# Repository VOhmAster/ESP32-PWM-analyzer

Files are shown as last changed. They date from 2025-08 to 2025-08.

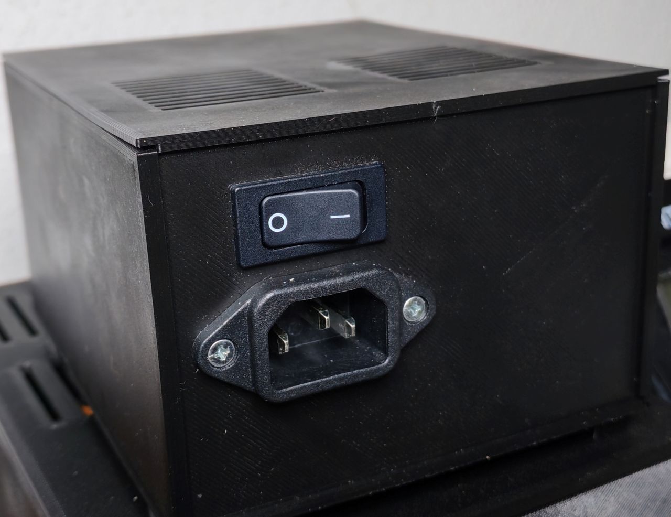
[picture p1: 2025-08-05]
Images/IMG_5.jpg

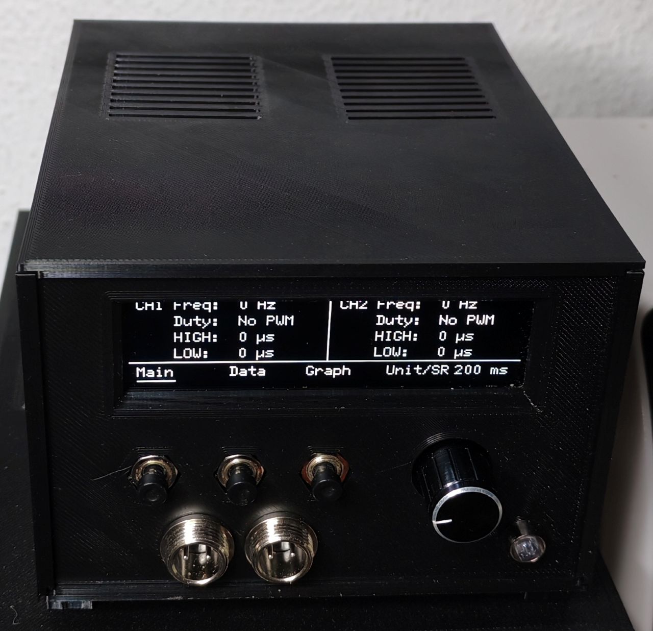
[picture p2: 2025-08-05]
Images/IMG_1.jpg

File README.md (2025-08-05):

# PWM Signal Analyzer

## Description
This project demonstrates a method of analyzing PWM signals with a focus on graphical, real-time visualization of the waveform. The main goal is to educate users on PWM analysis and provide a visual representation of signals as they change in real-time.

## **Features**
- **Real-time graphical display** of PWM waveforms
- **Adjustable frequency zoom levels** for different ranges (300 Hz – 2 MHz)
- **Simple user interface** with interactive menu options
- **Supports multiple PWM channels** (CH1, CH2)
- **Visual glitch detection** in the signals
- **Freeze mode** to stop updates for stable readings

### **Displayed Measurements**
- **Main Menu**
  - Frequency
  - Duty Cycle
  - High Time
  - Low Time
- **Data Menu**
  - Pulse Width
  - Period *(auto-switches between µs / ms based on value)*
  - Rise-to-Rise Interval
  - Glitch Count

## Additional Feature
The onboard RGB LED acts as a status indicator, adapting its color and behavior (pulsing or blinking) according to the current channel activity, frequency ranges, and duty cycle states.

## Hardware  
This project is built on an **ESP32-S3** and uses the following components:  
- **Two PWM signal inputs** (with optional RC delay network and 10k pull-down to GND).  
- **SSD1322 OLED display** (SPI interface).  
- **Rotary encoder** to adjust the update interval.  
- **Button interface** for menu navigation (3 dedicated buttons).  
- **RGB LED** as a status indicator (color and blink patterns show channel activity and duty states).  
- **220V → 5V (≥700 mA) power supply** power supply module.  
- **STDN-3A24-ADJ step-down module** for voltage regulation.  

### Pin Configuration
| Name | Pin | Description |
|---|-----|---|
| `PWM1_PIN` | 45  | Channel 1 PWM input |
| `PWM2_PIN` | 46  | Channel 2 PWM input |
| `ENC_A` | 17  | Rotary encoder pin A |
| `ENC_B` | 18  | Rotary encoder pin B |
| `ENC_SW` | 9 | Rotary encoder switch |
| `RED_PIN` | 37  | Red LED for status |
| `GREEN_PIN` | 36  | Green LED for status |
| `BLUE_PIN` | 38  | Blue LED for status |
| `SPI_MOSI_PIN` | 11  | OLED MOSI |
| `SPI_SCK_PIN` | 12  | OLED SCK |
| `SPI_CS_PIN` | 10  | OLED CS |
| `SPI_RES_PIN` | 13  | OLED Reset |
| `SPI_DC_PIN` | 14  | OLED DC |
| `BTN_MENU1` | 20  | Main menu |
| `BTN_MENU2` | 21  | Detailed data |
| `BTN_MENU3` | 47  | Graphical view |

### Important Notes
- A 10kΩ pull-down resistor is placed on the PWM input pins to improve signal stability and ensure reliable readings during startup.

## Installation
1. Clone the repository to your local machine:
    ```bash
    git clone https://github.com/VOhmAster/ESP32-PWM-analyzer.git
    ```
2. Open the project in Arduino IDE.
3. Upload the code to your ESP32 device.
4. Connect the PWM signal sources to the appropriate pins.

## Usage
- **Encoder Rotation**: Adjust the update interval between 50ms and 2000ms or toggle Freeze mode.
- **Encoder Button**: Change the display unit (Hz → kHz → MHz → Hz).
- **Display Navigation**: Use the dedicated buttons to switch between:
- **Main Display**: Displays real-time PWM signal data.
- **Detailed Data**: Shows more in-depth measurements such as high and low times.
- **Graph View**: Displays the waveform graph of the signals.
    
## Expansion
This project can be expanded by adding more hardware, allowing for higher-frequency PWM analysis and additional features like:
- Signal filtering and smoothing.
- Support for higher frequency ranges beyond the default setup.

## Files Included
- `PWM_analyzer.ino`: Main Arduino code.
- `Schematics/`: EasyEDA design files.
- `3D_Models/`: STL files for 3D printing the enclosure.

## Demo

**Load Response:**  
Load response

**Boot Sequence:**  
Boot

**OTA Firmware Update:**  
OTA

## License
This project is licensed under the MIT License - see the [LICENSE](LICENSE) file for details.

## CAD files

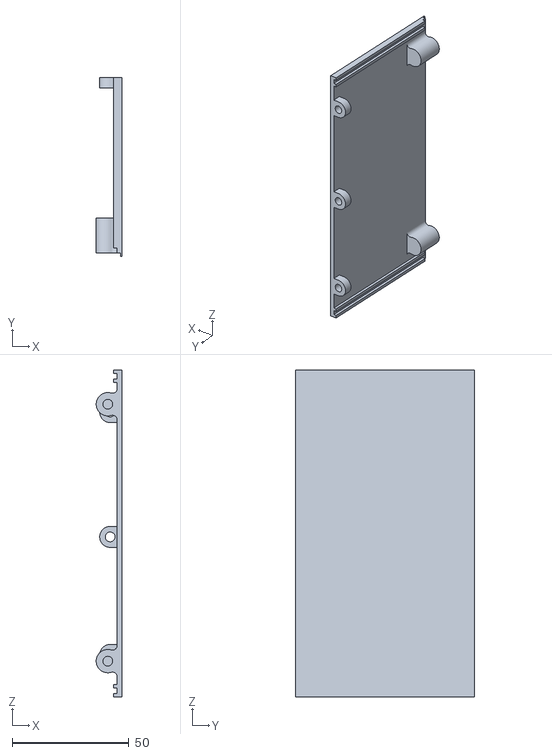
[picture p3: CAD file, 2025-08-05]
3D-models/Right_panel.stl
11.0 x 76.5 x 140.0

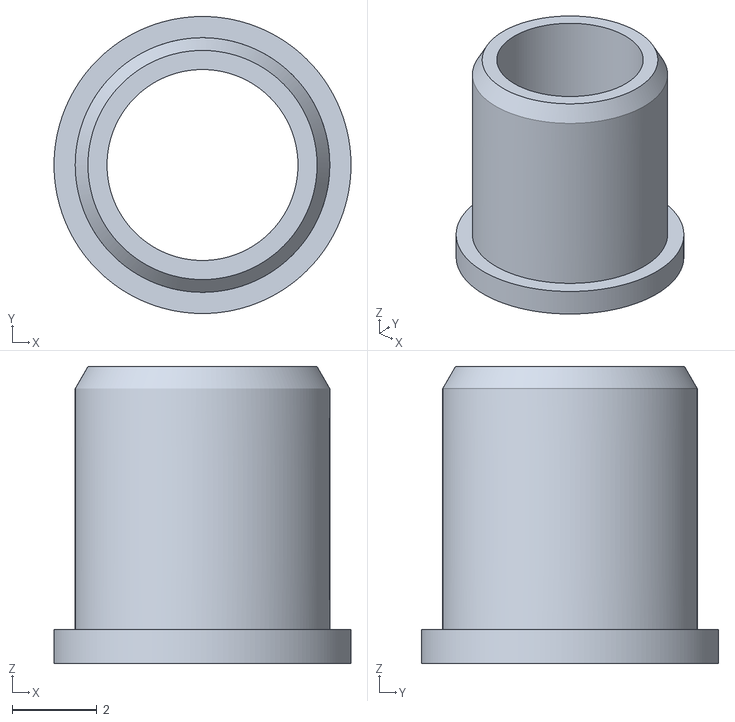
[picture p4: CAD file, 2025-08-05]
3D-models/rgb_led_holder.stl
7.00 x 7.00 x 7.00

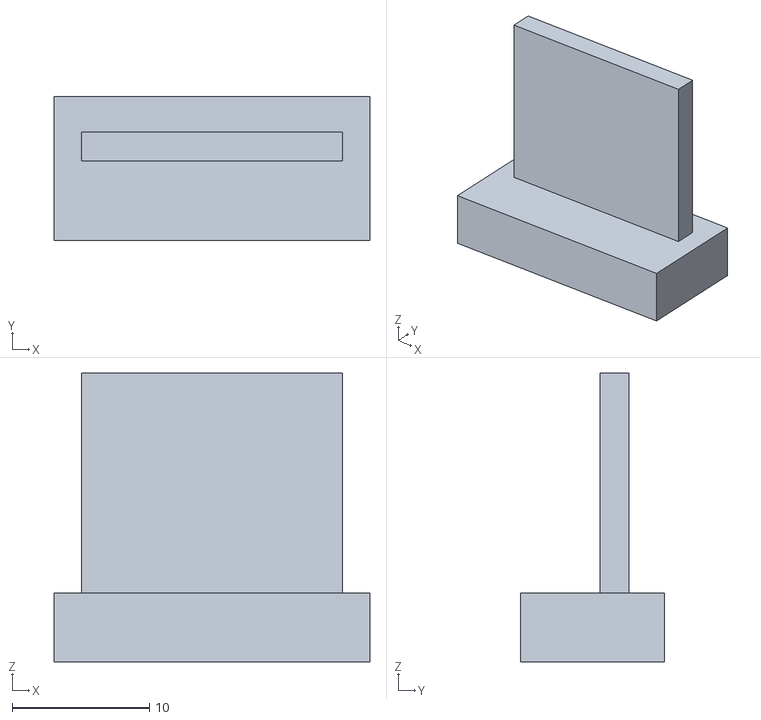
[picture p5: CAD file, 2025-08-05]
3D-models/Mounting_clip.stl
23.0 x 10.5 x 21.0

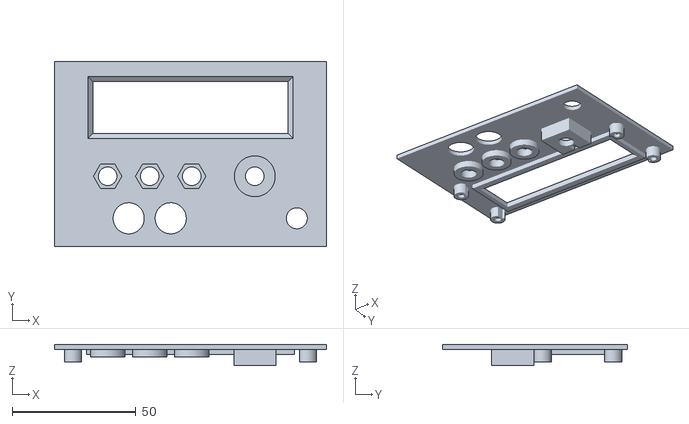
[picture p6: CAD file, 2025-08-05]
3D-models/Front_panel.stl
110.0 x 75.0 x 8.50

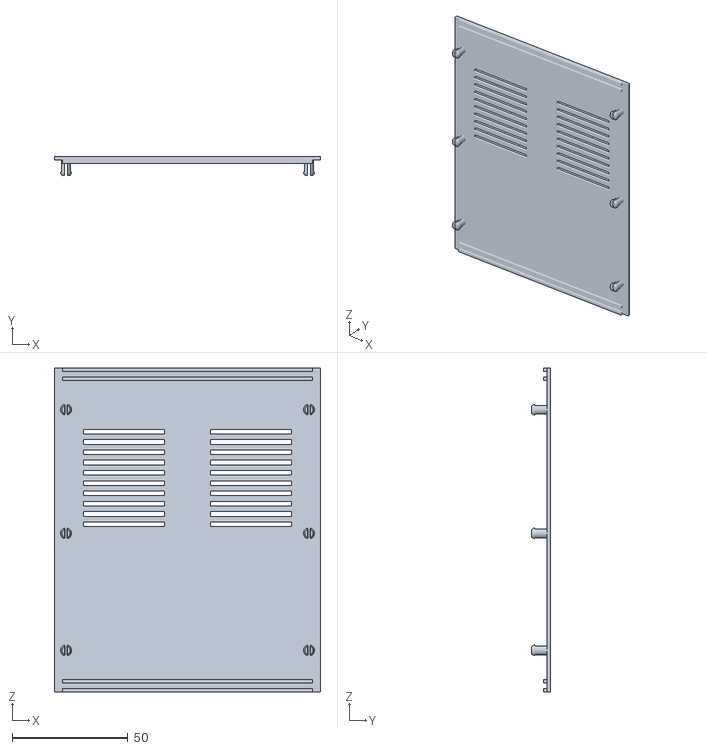
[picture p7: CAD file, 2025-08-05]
3D-models/Cover.stl
115.0 x 8.00 x 140.0

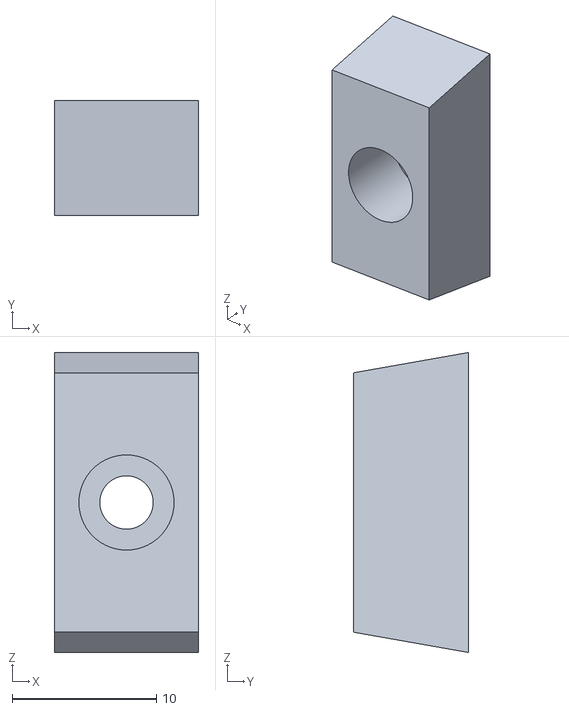
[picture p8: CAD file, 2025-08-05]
3D-models/Casefoot.stl
10.0 x 8.00 x 20.8

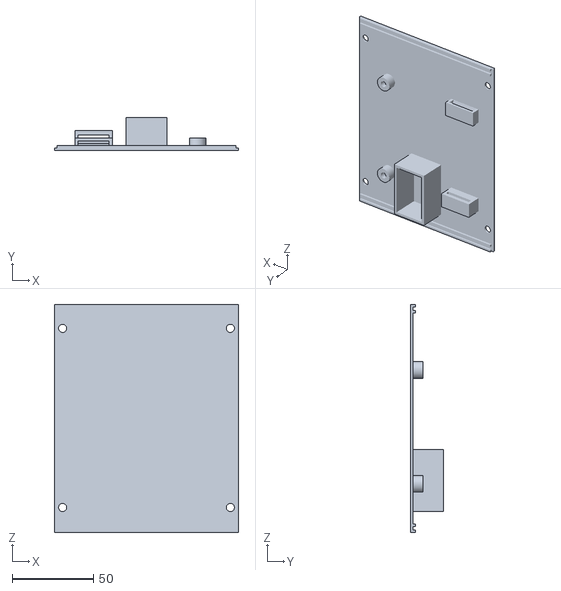
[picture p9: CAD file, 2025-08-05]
3D-models/Bottom_panel.stl
113.0 x 20.0 x 140.0

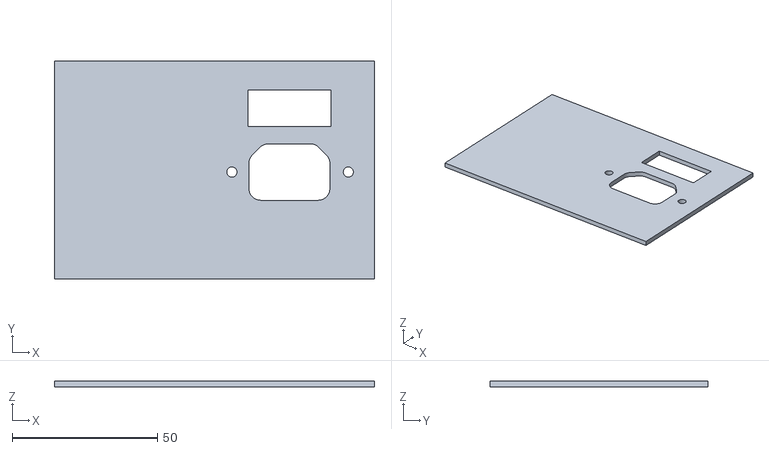
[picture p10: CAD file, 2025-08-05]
3D-models/Back_panel.stl
110.0 x 75.0 x 2.00

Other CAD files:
3D-models/Left_panel.stl

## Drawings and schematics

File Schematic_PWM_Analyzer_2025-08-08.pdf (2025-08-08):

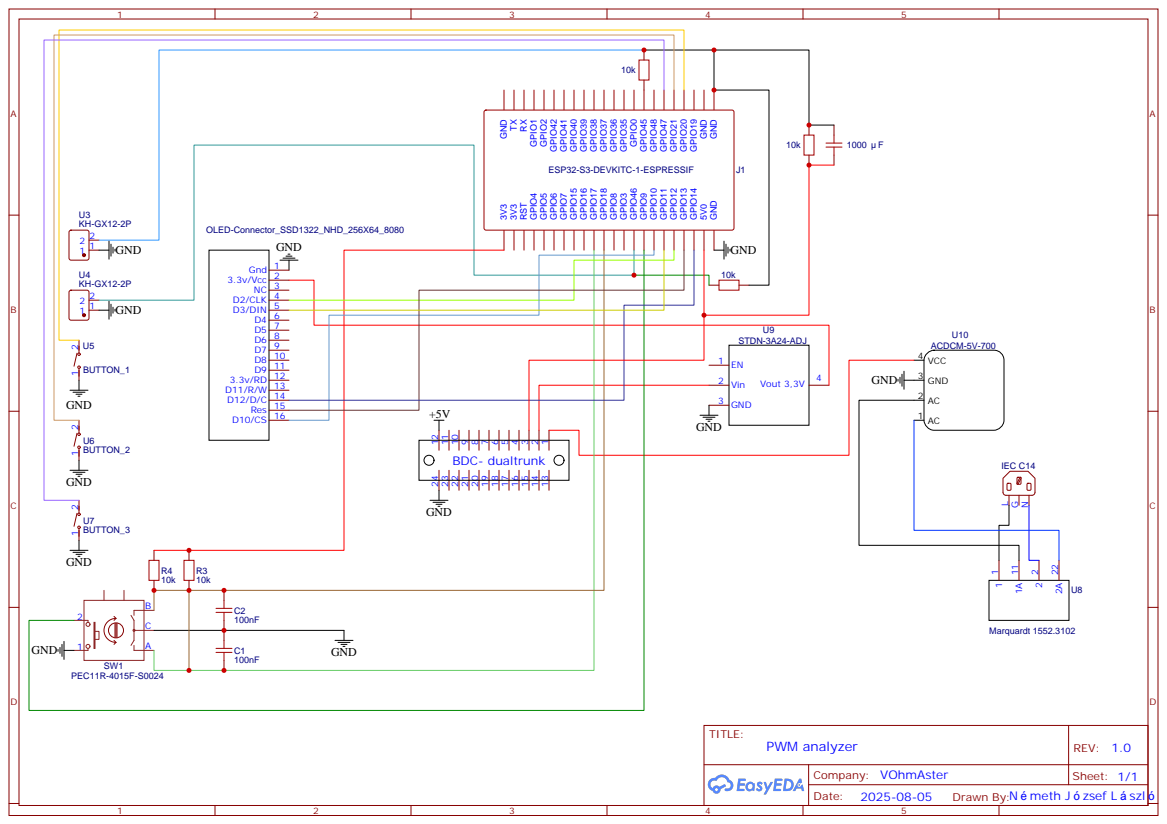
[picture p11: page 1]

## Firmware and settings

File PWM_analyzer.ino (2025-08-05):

// -------------------------
// 1. Libraries
// -------------------------
#include <SPI.h>
#include <U8g2lib.h>
#include <WiFi.h>
#include <ArduinoOTA.h>
#include <ESPmDNS.h>

// -------------------------
// 2. Wi-Fi settings
// -------------------------
const char* ssid = "YOUR SSID";
const char* password = "YOUR PASSWORD";

// -------------------------
// 3. GPIO definitions
// -------------------------

// RGB LED pins
#define RED_PIN    37
#define GREEN_PIN  36
#define BLUE_PIN   38

// Encoder pins
#define ENC_A   17
#define ENC_B   18
#define ENC_SW  9

// Menu buttons
#define BTN_MENU1  20
#define BTN_MENU2  21
#define BTN_MENU3  47

// PWM input pins
#define PWM1_PIN 45
#define PWM2_PIN 46

// SPI display pin mapping
#define SPI_MOSI_PIN 11
#define SPI_SCK_PIN  12
#define SPI_CS_PIN   10
#define SPI_RES_PIN  13
#define SPI_DC_PIN   14

// -------------------------
// 4. Display initialization
// -------------------------
U8G2_SSD1322_NHD_256X64_F_4W_HW_SPI u8g2(
  U8G2_R2,
  /*CS=*/SPI_CS_PIN,
  /*DC=*/SPI_DC_PIN,
  /*RESET=*/SPI_RES_PIN
);

// -------------------------
// 5. Variables for display rendering
// -------------------------
int dutyX = 220, dutyY = 7, barWidth = 8, maxHeight = 15, offset = 20;

const int waveformStartX = 40;
const int waveformEndX = 200;
const int waveformWidth = waveformEndX - waveformStartX;

uint8_t waveform1[waveformWidth] = {0};
uint8_t waveform2[waveformWidth] = {0};
#define WAVEFORM_EMPTY 255

int yTop1 = 10, yBottom1 = 20;
int yTop2 = 35, yBottom2 = 45;

int frequDisplayUnit = 0;  // 0: Hz, 1: kHz, 2: MHz

// -------------------------
// 6. Zoom and view state
// -------------------------
int freqZoomLevel = 0;         // 0: 300-999Hz, 1: 1k-499kHz, 2: 500k-999kHz, 3: 1M-2MHz
const int maxZoomLevel = 3;
bool freezeMode = false;

// -------------------------
// 7. Menu system variables
// -------------------------
byte selectedMenu = 0;
static byte lastSelectedMenu = 255;
bool prevBtn1 = HIGH, prevBtn2 = HIGH, prevBtn3 = HIGH;

// -------------------------
// 8. Encoder state handling
// -------------------------
int lastEncoderValue = 0;
volatile int encoderValue = 0;
int lastA = 0;
int lastB = 0;
int lastButtonState = HIGH;

// -------------------------
// 9. PWM signal processing – timing and detection
// -------------------------
unsigned long lastISRTime1 = 0;
unsigned long lastISRTime2 = 0;

volatile unsigned long riseTime1 = 0, pwmPeriod1 = 0, highTime1 = 0, lowTime1 = 0;
volatile unsigned long riseTime2 = 0, pwmPeriod2 = 0, highTime2 = 0, lowTime2 = 0;

volatile unsigned long dutyCycle1 = 0;
volatile unsigned long dutyCycle2 = 0;

// -------------------------
// 10. Averaged frequencies and strings for display
// -------------------------
float avgFreq1 = 0, avgFreq2 = 0;
String freq1Str = "", unit1 = "";
String freq2Str = "", unit2 = "";

// -------------------------
// 11. Sampling buffers
// -------------------------
#define NUM_SAMPLES 8

// CH1 - First channel
volatile unsigned long periods1[NUM_SAMPLES] = {0};
volatile unsigned long freqPeriods1[NUM_SAMPLES] = {0};
volatile unsigned long dutyCycles1[NUM_SAMPLES] = {0};
volatile byte sampleIndex1 = 0;

// CH2 - Second channel
volatile unsigned long periods2[NUM_SAMPLES] = {0};
volatile unsigned long freqPeriods2[NUM_SAMPLES] = {0};
volatile unsigned long dutyCycles2[NUM_SAMPLES] = {0};
volatile byte sampleIndex2 = 0;

// -------------------------
// 12. PWM state and counters (for waveform rendering, etc.)
// -------------------------
int state1 = 0, counter1 = 0;
int state2 = 0, counter2 = 0;

int highLen1 = 3, lowLen1 = 3;
int highLen2 = 3, lowLen2 = 3;

// -------------------------
// 13. Other settings
// -------------------------
#define SIGNAL_TIMEOUT 200        // Timeout detection in milliseconds
unsigned int updateInterval = 200;  // Data refresh interval

bool hasSignal1() {
  return (millis() - (lastISRTime1 / 1000)) < SIGNAL_TIMEOUT;
}

bool hasSignal2() {
  return (millis() - (lastISRTime2 / 1000)) < SIGNAL_TIMEOUT;
}

void setup() {
  // Serial for debugging if needed
  // Serial.begin(115200);

  // --- OLED display initialization ---
  u8g2.setBusClock(2000000);
  u8g2.begin();
  u8g2.setPowerSave(1);

  // Set RGB LED pins as outputs
  pinMode(RED_PIN, OUTPUT);
  pinMode(GREEN_PIN, OUTPUT);
  pinMode(BLUE_PIN, OUTPUT);

  // Configure PWM channels using LEDC API
  ledcAttach(RED_PIN, 5000, 8);    // Frequency: 5kHz, resolution: 8-bit
  ledcAttach(GREEN_PIN, 5000, 8);
  ledcAttach(BLUE_PIN, 5000, 8);

  u8g2.setFont(u8g2_font_ncenB08_tr);

  // Initialize waveform buffers
  for (int i = 0; i < waveformWidth; i++) {
    waveform1[i] = WAVEFORM_EMPTY;
    waveform2[i] = WAVEFORM_EMPTY;
  }

  // --- Wi-Fi connection ---
  WiFi.mode(WIFI_STA);
  WiFi.begin(ssid, password);

   u8g2.setPowerSave(0);

  unsigned long wifiStart = millis();
  bool wifiOk = false;

  while (millis() - wifiStart < 5000) {
    if (WiFi.status() == WL_CONNECTED) {
      wifiOk = true;
      break;
    }
    u8g2.clearBuffer();
    u8g2.drawStr(0, 12, "Connecting to WiFi...");
    u8g2.sendBuffer();
    delay(500);
  }

  if (wifiOk) {
    u8g2.clearBuffer();
    u8g2.drawStr(0, 12, "WiFi OK");
    String ipText = "IP: " + WiFi.localIP().toString();
    u8g2.drawStr(0, 28, ipText.c_str());
    u8g2.sendBuffer();
    delay(2000);

    // --- OTA configuration (only if WiFi is available) ---
    ArduinoOTA.setHostname("esp32-pwm-analyzer");

    ArduinoOTA.onStart([]() {
      String type;
      if (ArduinoOTA.getCommand() == U_FLASH) type = "Sketch";
      else type = "Filesystem";
      String msg = "Starting: " + type;

      u8g2.clearBuffer();
      u8g2.drawStr(0, 12, "OTA update starting");
      u8g2.drawStr(0, 28, msg.c_str());
      u8g2.sendBuffer();
    });

    ArduinoOTA.onEnd([]() {
      u8g2.clearBuffer();
      u8g2.drawStr(0, 12, "Update complete!");
      u8g2.sendBuffer();
    });

    ArduinoOTA.onProgress([](unsigned int progress, unsigned int total) {
      uint8_t percent = progress / (total / 100);
      String msg = "Updating: " + String(percent) + "%";

      u8g2.clearBuffer();
      u8g2.drawStr(0, 12, msg.c_str());
      u8g2.sendBuffer();
    });

    ArduinoOTA.onError([](ota_error_t error) {
      u8g2.clearBuffer();
      u8g2.drawStr(0, 12, "OTA Error!");

      switch (error) {
        case OTA_AUTH_ERROR:
          u8g2.drawStr(0, 28, "Auth failed");
          break;
        case OTA_BEGIN_ERROR:
          u8g2.drawStr(0, 28, "Begin failed");
          break;
        case OTA_CONNECT_ERROR:
          u8g2.drawStr(0, 28, "Connect failed");
          break;
        case OTA_RECEIVE_ERROR:
          u8g2.drawStr(0, 28, "Receive failed");
          break;
        case OTA_END_ERROR:
          u8g2.drawStr(0, 28, "End failed");
          break;
      }

      u8g2.sendBuffer();
    });

    ArduinoOTA.begin();
  } else {
    u8g2.clearBuffer();
    u8g2.drawStr(0, 12, "WiFi not available");
    u8g2.drawStr(0, 28, "Starting offline");
    u8g2.sendBuffer();
    delay(2000);
  }

  // Input pin setup
  pinMode(ENC_A, INPUT);
  pinMode(ENC_B, INPUT);
  pinMode(ENC_SW, INPUT_PULLUP);

  pinMode(BTN_MENU1, INPUT_PULLUP);
  pinMode(BTN_MENU2, INPUT_PULLUP);
  pinMode(BTN_MENU3, INPUT_PULLUP);

  pinMode(PWM1_PIN, INPUT);
  pinMode(PWM2_PIN, INPUT);

  delay(1000);

  // Interrupts
  attachInterrupt(digitalPinToInterrupt(ENC_A), encoderISR, CHANGE);
  attachInterrupt(digitalPinToInterrupt(PWM1_PIN), pwmISR_CH1, CHANGE);
  attachInterrupt(digitalPinToInterrupt(PWM2_PIN), pwmISR_CH2, CHANGE);

  // Initialize encoder state
  lastA = digitalRead(ENC_A);
  lastB = digitalRead(ENC_B);
  
}

void loop() {
  ArduinoOTA.handle();  
  
  ReadEncoderButton();

  handleStatusLED(hasSignal1(), hasSignal2());

  int btn1 = digitalRead(BTN_MENU1);
  int btn2 = digitalRead(BTN_MENU2);
  int btn3 = digitalRead(BTN_MENU3);

  if (btn1 == LOW && prevBtn1 == HIGH) selectedMenu = 0;  // Main screen
  if (btn2 == LOW && prevBtn2 == HIGH) selectedMenu = 1;  // Detailed screen
  if (btn3 == LOW && prevBtn3 == HIGH) selectedMenu = 2;  // Graphical screen

  prevBtn1 = btn1;
  prevBtn2 = btn2;
  prevBtn3 = btn3;

  drawMenu();
}

void drawMenu() {
  u8g2.clearBuffer();

  // Underline the active menu item
  switch (selectedMenu) {
    case 0: u8g2.drawHLine(5, 63, 25); break;
    case 1: u8g2.drawHLine(65, 63, 25); break;
    case 2: u8g2.drawHLine(115, 63, 30); break;
  }

  // Render content based on selected menu
  switch (selectedMenu) {
    case 0: MainDisplay(); break;
    case 1: drawDetailScreen(); break;
    case 2: drawGraphScreen(); break;
  }

  u8g2.sendBuffer();
} 

void drawDetailScreen() {
  // -----------------------------
  // 1. Static variables (retain values between calls)
  // -----------------------------
  static unsigned long lastUpdate = 0;

  // Values for display that do not change every loop
  static float dutyPct1 = 0, dutyPct2 = 0;
  static unsigned long riseToRiseCH1 = 0, riseToRiseCH2 = 0;
  static uint8_t glitchCountCH1 = 0, glitchCountCH2 = 0;
  static unsigned long savedPwmPeriod1 = 0, savedPwmPeriod2 = 0;

  // Previous rising edge timestamps for both channels
  static unsigned long prevRiseTime1 = 0;
  static unsigned long prevRiseTime2 = 0;

  // -----------------------------
  // 2. Read encoder (for update interval adjustment)
  // -----------------------------
  handleEncoderUpdateInterval();

  // -----------------------------
  // 3. Timing: update only when due and not in freeze mode
  // -----------------------------
  unsigned long currentMillis = millis();
  if (!freezeMode && currentMillis - lastUpdate >= updateInterval) {
    lastUpdate = currentMillis;

    // Timeout handling: reset data if ISR hasn't triggered recently
    if ((micros() - lastISRTime1) > 100000) {
      highTime1 = 0;
      pwmPeriod1 = 0;
      lowTime1 = 0;
      dutyPct1 = 0;
      savedPwmPeriod1 = 0;
      riseToRiseCH1 = 0;
      glitchCountCH1 = 0;
    }

    if ((micros() - lastISRTime2) > 100000) {
      highTime2 = 0;
      pwmPeriod2 = 0;
      lowTime2 = 0;
      dutyPct2 = 0;
      savedPwmPeriod2 = 0;
      riseToRiseCH2 = 0;
      glitchCountCH2 = 0;
    }

    // Save values for rendering
    savedPwmPeriod1 = pwmPeriod1;
    savedPwmPeriod2 = pwmPeriod2;

    // -----------------------------
    // 4. CH1 – calculations
    // -----------------------------
    dutyPct1 = (pwmPeriod1 > 0) ? (float)highTime1 / pwmPeriod1 * 100.0 : 0;
    riseToRiseCH1 = (riseTime1 > prevRiseTime1) ? (riseTime1 - prevRiseTime1) : 0;
    prevRiseTime1 = riseTime1;

    glitchCountCH1 = 0;
    if (highTime1 < 10) glitchCountCH1++;
    if (lowTime1 < 10) glitchCountCH1++;

    // -----------------------------
    // 5. CH2 – calculations
    // -----------------------------
    dutyPct2 = (pwmPeriod2 > 0) ? (float)highTime2 / pwmPeriod2 * 100.0 : 0;
    riseToRiseCH2 = (riseTime2 > prevRiseTime2) ? (riseTime2 - prevRiseTime2) : 0;
    prevRiseTime2 = riseTime2;

    glitchCountCH2 = 0;
    if (highTime2 < 10) glitchCountCH2++;
    if (lowTime2 < 10) glitchCountCH2++;
  }

  // -----------------------------
  // 6. Display update (runs every loop)
  // -----------------------------
  u8g2.setFont(u8g2_font_6x12_t_symbols);
  char buf[32];

  // Show freeze status
  if (freezeMode) {
    sprintf(buf, "Freeze");
  } else {
    sprintf(buf, "%u ms", updateInterval);
  }
  u8g2.drawStr(213, 60, buf);

  // -----------------------------
  // 7. CH1 – display values
  // -----------------------------
  u8g2.drawStr(5, 10, "CH1");
  sprintf(buf, "Pulse:  %.1f %%", dutyPct1);                u8g2.drawStr(30, 10, buf);
  if (savedPwmPeriod1 > 9999) {
     sprintf(buf, "Period: %lu ms", savedPwmPeriod1 / 1000);
} else {
     sprintf(buf, "Period: %lu \xB5s", savedPwmPeriod1);
}
      u8g2.drawStr(30, 22, buf);
  sprintf(buf, "R->R:  %.1f ms", riseToRiseCH1 / 1000.0);   u8g2.drawStr(30, 34, buf);
  if (glitchCountCH1 == 0) strcpy(buf, "Glitch: none");
  else sprintf(buf, "Glitch: %u short", glitchCountCH1);
  u8g2.drawStr(30, 46, buf);

  // -----------------------------
  // 8. CH2 – display values
  // -----------------------------
  u8g2.drawStr(135, 10, "CH2");
  sprintf(buf, "Pulse:  %.1f %%", dutyPct2);                u8g2.drawStr(160, 10, buf);
 if (savedPwmPeriod2 > 9999) {
    sprintf(buf, "Period: %lu ms", savedPwmPeriod2 / 1000);
} else {
    sprintf(buf, "Period: %lu \xB5s", savedPwmPeriod2);
}
    u8g2.drawStr(160, 22, buf);
  sprintf(buf, "R->R:  %.1f ms", riseToRiseCH2 / 1000.0);   u8g2.drawStr(160, 34, buf);
  if (glitchCountCH2 == 0) strcpy(buf, "Glitch: none");
  else sprintf(buf, "Glitch: %u short", glitchCountCH2);
  u8g2.drawStr(160, 46, buf);

  // -----------------------------
  // 9. Bottom menu rendering
  // -----------------------------
  drawBottomMenu();
}


void drawGraphScreen() {
  // -----------------------------
  // 1. Static variables to retain values between iterations
  // -----------------------------
  static unsigned long lastUpdate = 0;
  static float avgDutyCycle1 = 0;
  static float avgDutyCycle2 = 0;

  // -----------------------------
  // 2. Handle encoder (for adjusting update interval)
  // -----------------------------
  handleEncoderUpdateInterval();

  // -----------------------------
  // 3. Timed update (only if not frozen)
  // -----------------------------
  unsigned long currentMillis = millis();
  if (!freezeMode && currentMillis - lastUpdate >= updateInterval) {
    lastUpdate = currentMillis;

    // -----------------------------
    // 4. Check PWM validity on both channels
    // (If no data, set estimated value)
    // -----------------------------
    bool pwm1_active = (micros() - lastISRTime1) < 100000;
    bool valid_pwm1 = pwm1_active && avgDutyCycle1 > 0.0 && avgDutyCycle1 < 100.0;
    if (!valid_pwm1 && digitalRead(PWM1_PIN) == HIGH) avgDutyCycle1 = 100.0;
    else if (!valid_pwm1) avgDutyCycle1 = 0.0;

    bool pwm2_active = (micros() - lastISRTime2) < 100000;
    bool valid_pwm2 = pwm2_active && avgDutyCycle2 > 0.0 && avgDutyCycle2 < 100.0;
    if (!valid_pwm2 && digitalRead(PWM2_PIN) == HIGH) avgDutyCycle2 = 100.0;
    else if (!valid_pwm2) avgDutyCycle2 = 0.0;

    // -----------------------------
    // 5. Get averaged values (from external functions)
    // -----------------------------
    avgDutyCycle1 = getAverageDuty1(); 
    avgDutyCycle2 = getAverageDuty2(); 
    float freq1 = getAverageFreq1();  
    float freq2 = getAverageFreq2();  

    // -----------------------------
    // 6. Calculate waveform height based on frequency
    // -----------------------------
    int height1 = mapFrequencyToHeight(freq1);
    int height2 = mapFrequencyToHeight(freq2);

    yTop1 = yBottom1 - height1;
    yTop2 = yBottom2 - height2;

    // -----------------------------
    // 7. Calculate waveform segments based on duty cycle
    // -----------------------------
    int fullCycleLen = 20;
    highLen1 = max(1, (int)(fullCycleLen * avgDutyCycle1 / 100.0));
    lowLen1  = fullCycleLen - highLen1;
    highLen2 = max(1, (int)(fullCycleLen * avgDutyCycle2 / 100.0));
    lowLen2  = fullCycleLen - highLen2;

    // -----------------------------
    // 8. Scroll waveform left by 1 pixel
    // -----------------------------
    memmove(&waveform1[0], &waveform1[1], waveformWidth - 1);
    memmove(&waveform2[0], &waveform2[1], waveformWidth - 1);

    // -----------------------------
    // 9. CH1 – state machine adds new pixel
    // -----------------------------
    if ((int)avgDutyCycle1 == 100) {
      waveform1[waveformWidth - 1] = 1;
    } else if ((int)avgDutyCycle1 == 0) {
      waveform1[waveformWidth - 1] = 0;
    } else {
      switch (state1) {
        case 0: waveform1[waveformWidth - 1] = 0; if (++counter1 >= lowLen1) { counter1 = 0; state1 = 1; } break;
        case 1: waveform1[waveformWidth - 1] = 2; state1 = 2; break;
        case 2: waveform1[waveformWidth - 1] = 1; if (++counter1 >= highLen1 - 1) { counter1 = 0; state1 = 3; } break;
        case 3: waveform1[waveformWidth - 1] = 3; state1 = 0; break;
      }
    }

    // -----------------------------
    // 10. CH2 – state machine adds new pixel
    // -----------------------------
    if ((int)avgDutyCycle2 == 100) {
      waveform2[waveformWidth - 1] = 1;
    } else if ((int)avgDutyCycle2 == 0) {
      waveform2[waveformWidth - 1] = 0;
    } else {
      switch (state2) {
        case 0: waveform2[waveformWidth - 1] = 0; if (++counter2 >= lowLen2) { counter2 = 0; state2 = 1; } break;
        case 1: waveform2[waveformWidth - 1] = 2; state2 = 2; break;
        case 2: waveform2[waveformWidth - 1] = 1; if (++counter2 >= highLen2 - 1) { counter2 = 0; state2 = 3; } break;
        case 3: waveform2[waveformWidth - 1] = 3; state2 = 0; break;
      }
    }
  }

  // -----------------------------
  // 11. UI elements on the display
  // -----------------------------
  char buf[10];
  if (freezeMode) {
    sprintf(buf, "Freeze");
  } else {
    sprintf(buf, "%u ms", updateInterval);
  }
  u8g2.drawStr(213, 60, buf);   

  u8g2.drawStr(5, 12, "CH1 ");
  u8g2.drawStr(5, 34, "CH2 ");

  // -----------------------------
  // 12. Draw CH1 duty cycle bar
  // -----------------------------
  int dutyHeight = (int)(maxHeight * (avgDutyCycle1 / 100.0));
  u8g2.drawFrame(dutyX - 2, dutyY - 2, barWidth + 4, maxHeight + 4);
  u8g2.drawBox(dutyX, dutyY + (maxHeight - dutyHeight), barWidth, dutyHeight);
  char dutyText[10];
  snprintf(dutyText, sizeof(dutyText), "%d%%", (int)avgDutyCycle1);
  u8g2.drawStr(dutyX + barWidth + 4, dutyY + maxHeight / 2, dutyText);

  // -----------------------------
  // 13. Draw CH2 duty cycle bar
  // -----------------------------
  int dutyX2 = 220;
  int dutyY2 = dutyY + maxHeight + 6;
  int dutyHeight2 = (int)(maxHeight * (avgDutyCycle2 / 100.0));
  u8g2.drawFrame(dutyX2 - 2, dutyY2 - 2, barWidth + 4, maxHeight + 4);
  u8g2.drawBox(dutyX2, dutyY2 + (maxHeight - dutyHeight2), barWidth, dutyHeight2);
  char dutyText2[10];
  snprintf(dutyText2, sizeof(dutyText2), "%d%%", (int)avgDutyCycle2);
  u8g2.drawStr(dutyX2 + barWidth + 4, dutyY2 + maxHeight / 2, dutyText2);

  // -----------------------------
  // 14. Draw waveform for CH1
  // -----------------------------
  for (int x = 0; x < waveformWidth; x++) {
    int screenX = x + waveformStartX;
    switch (waveform1[x]) {
      case 0: u8g2.drawPixel(screenX, yBottom1); break;
      case 1: u8g2.drawPixel(screenX, yTop1); break;
      case 2: u8g2.drawLine(screenX, yBottom1, screenX, yTop1); break;
      case 3: u8g2.drawLine(screenX, yTop1, screenX, yBottom1); break;
      default: break;
    }
  }

  // -----------------------------
  // 15. Draw waveform for CH2
  // -----------------------------
  for (int x = 0; x < waveformWidth; x++) {
    int screenX = x + waveformStartX;
    switch (waveform2[x]) {
      case 0: u8g2.drawPixel(screenX, yBottom2); break;
      case 1: u8g2.drawPixel(screenX, yTop2); break;
      case 2: u8g2.drawLine(screenX, yBottom2, screenX, yTop2); break;
      case 3: u8g2.drawLine(screenX, yTop2, screenX, yBottom2); break;
      case WAVEFORM_EMPTY: default: break;
    }
  }

  // -----------------------------
  // 16. Draw bottom menu
  // -----------------------------
  drawBottomMenu();
}

void pushWaveform(uint8_t* waveform, float duty, int width) {
  int pulseWidth = (int)(width * (duty / 100.0));
  pulseWidth = constrain(pulseWidth, 1, width - 2);  // Do not allow 0 or too large
  int lowWidth = width - pulseWidth;

  // Shift left
  for (int i = 0; i < waveformWidth - width; i++) {
    waveform[i] = waveform[i + width];
  }

  // Write new waveform
  int idx = waveformWidth - width;
  waveform[idx++] = 2; // Rising edge
  for (int i = 1; i < pulseWidth - 1; i++) waveform[idx++] = 1; // HIGH
  waveform[idx++] = 3; // Falling edge
  for (int i = 0; i < lowWidth - 1; i++) waveform[idx++] = 0; // LOW
}

void drawWaveform(uint8_t* waveform, int yTop, int yBottom) {
  for (int x = 0; x < waveformWidth; x++) {
    switch (waveform[x]) {
      case 0: u8g2.drawPixel(x, yBottom); break;        // LOW
      case 1: u8g2.drawPixel(x, yTop); break;           // HIGH
      case 2: u8g2.drawLine(x, yBottom, x, yTop); break; // Rising edge
      case 3: u8g2.drawLine(x, yTop, yBottom, x); break; // Falling edge
    }
  }
}
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

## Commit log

2025-08-05 Fixed boot issues, added dynamic unit display for period
    Delays the interrupts on the input pins to ensure stable booting of the system.
    Additionally, the period value now dynamically switches between microseconds (µs) and milliseconds (ms)
    depending on the magnitude for improved readability.
    [PWM_analyzer.ino]
2025-08-08 Update schematic with power delay circuit
    Replaced the previous analyzer schematic with a new version including a 1000µF capacitor and 10kΩ discharge resistor on the power line. This change ensures stable boot behavior of the ESP32 by adding a short power hold-up delay. Old schematic removed.
